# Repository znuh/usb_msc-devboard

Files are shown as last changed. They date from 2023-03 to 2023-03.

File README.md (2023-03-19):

# Devboard for USB mass storage


EDA: [KiCad7](https://www.kicad.org/)

## Parts
* MCU: [STM32F730R8Tx](https://www.st.com/en/microcontrollers-microprocessors/stm32f730r8.html) (or compatible)
* Mass storage: MicroSD via [DM3D-SF](https://www.hirose.com/product/series/DM3#) socket (attached to SDMMC1 of STM32)
* [USB3318](https://www.microchip.com/en-us/product/USB3318) USB high speed PHY
* 3.3V voltage regulator: [AP7313-33SR](https://www.diodes.com/part/view/AP7313/) or compatible
* PCB: 4 layer (Sig1, GND, 3.3V, Sig2) stackup
* 1x USB-C, 1x Micro USB
* 3x 0603 LEDs (power, user1, user2)
* 1x Button (Bootloader + user defined)
* passives: 0402 and 0603
* all componentes are on top, none on bottom

## Notes
* USB-C connector for hi-speed USB
* Micro USB connector for dev/debugging/DFU bootloader
* Testpads on bottom for UART (debugging, etc.)
* only one 13MHz crystal, connected to STM32 - MCO1 output of STM32 clocks USB PHY
* serial termination resistors in all clock lines

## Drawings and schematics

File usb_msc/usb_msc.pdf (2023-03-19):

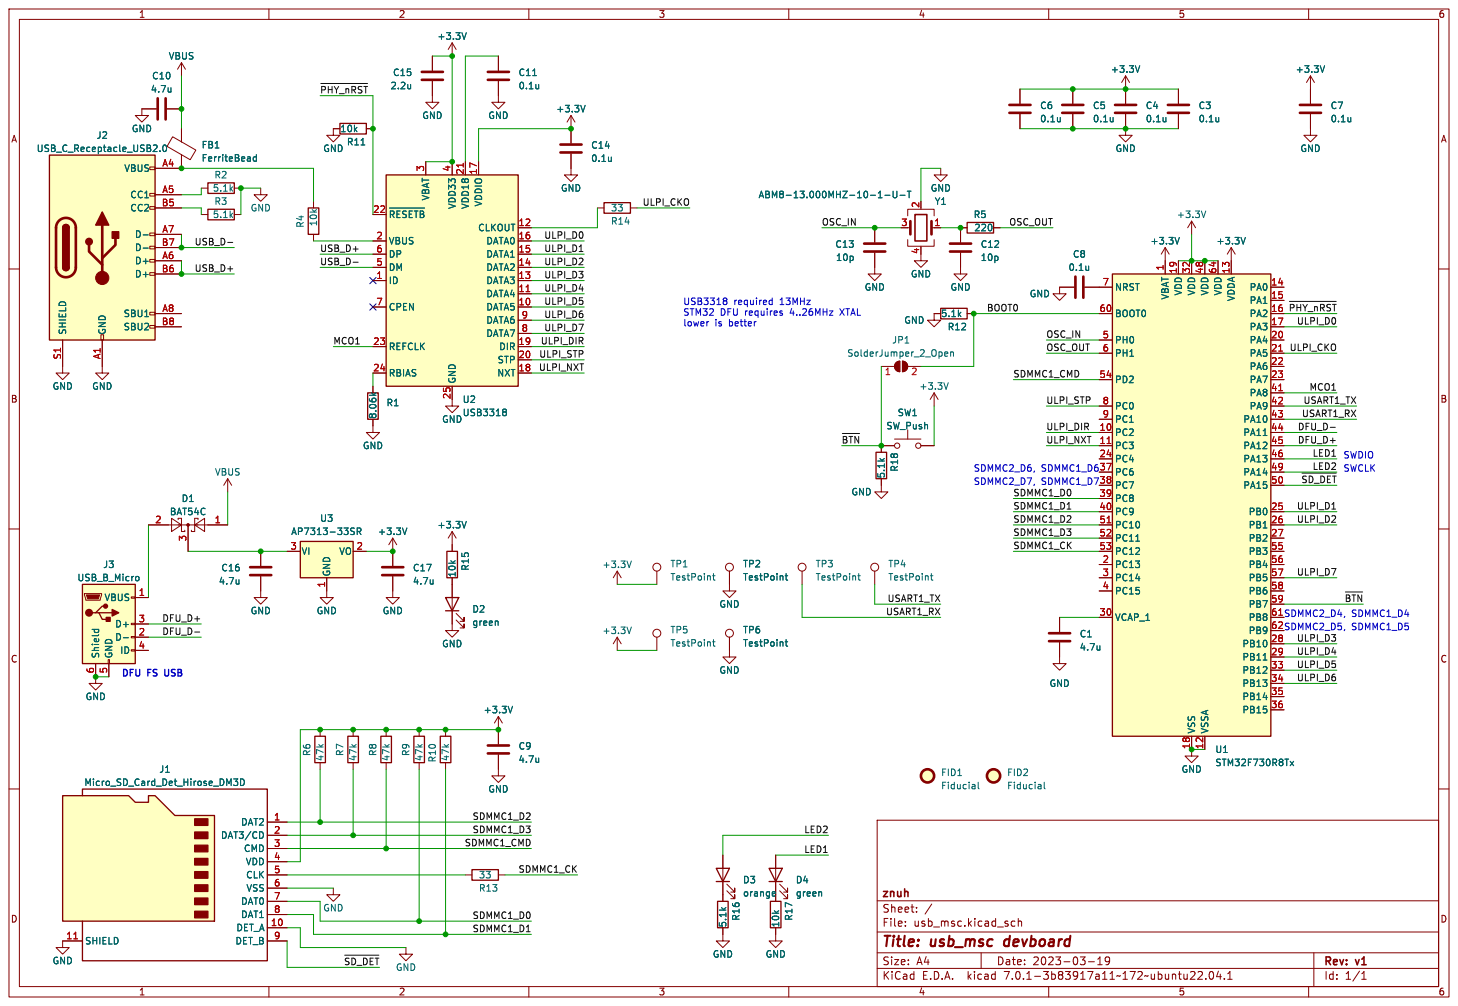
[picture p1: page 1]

4 DM 5 DP 6 CPEN 7 DATA7 8 DATA6 9 U2 USB3318 GND GND

4 DM 5 DP 6 CPEN 7 DATA7 8 DATA6 9 GND GND

1 PC2 10 PC3 11 VSSA 12 VDDA 13 PA0 14 PA1 15 PA2 16 PA3 17 VSS 18 VDD 19 PC13 2 PA4 20 PA5 21 PA6 22 PA7 23 PC4 24 PB0 25 PB1 26 PB2 27 PB10 28 PB11 29 PC14 3 VCAP_1 30 VDD 32 PB12 33 PB13 34 PB14 35 PB15 36 PC6 37 PC7 38 PC8 39 PC15 4 PC9 40 PA8 41 PA9 42 PA10 43 PA11 44 PA12 45 PA13 46 VDD 48 PA14 49 PH0 5 PA15 50 PC10 51 PC11 52 PC12 53 PD2 54 PB3 55 PB4 56 PB5 57 PB6 58 PB7 59 PH1 6 BOOT0 60 PB8 61 PB9 62 VDD 64 NRST 7 PC0 8 PC1 9 C14

1 PC2 10 PC3 11 VSSA 12 VDDA 13 PA0 14 PA1 15 PA2 16 PA3 17 VSS 18 VDD 19 PC13 2 PA4 20 PA5 21 PA6 22 PA7 23 PC4 24 PB0 25 PB1 26 PB2 27 PB10 28 PB11 29 PC14 3 VCAP_1 30 VDD 32 PB12 33 PB13 34 PB14 35 PB15 36 PC6 37 PC7 38 PC8 39 PC15 4 PC9 40 PA8 41 PA9 42 PA10 43 PA11 44 PA12 45 PA13 46 VDD 48 PA14 49 PH0 5 PA15 50 PC10 51 PC11 52 PC12 53 PD2 54 PB3 55 PB4 56 PB5 57 PB6 58 PB7 59 PH1 6 BOOT0 60 PB8 61 PB9 62 VDD 64 NRST 7 PC0 8 PC1 9 U1STM32F730R8Tx

SDMMC2_D5, SDMMC1_D5 SDMMC2_D7, SDMMC1_D7 SDMMC2_D6, SDMMC1_D6 USB3318 required 13MHz STM32 DFU requires 4..26MHz XTAL
+3.3V GND

File: usb_msc.kicad_sch Sheet: / znuh GND
green R17 10k GND

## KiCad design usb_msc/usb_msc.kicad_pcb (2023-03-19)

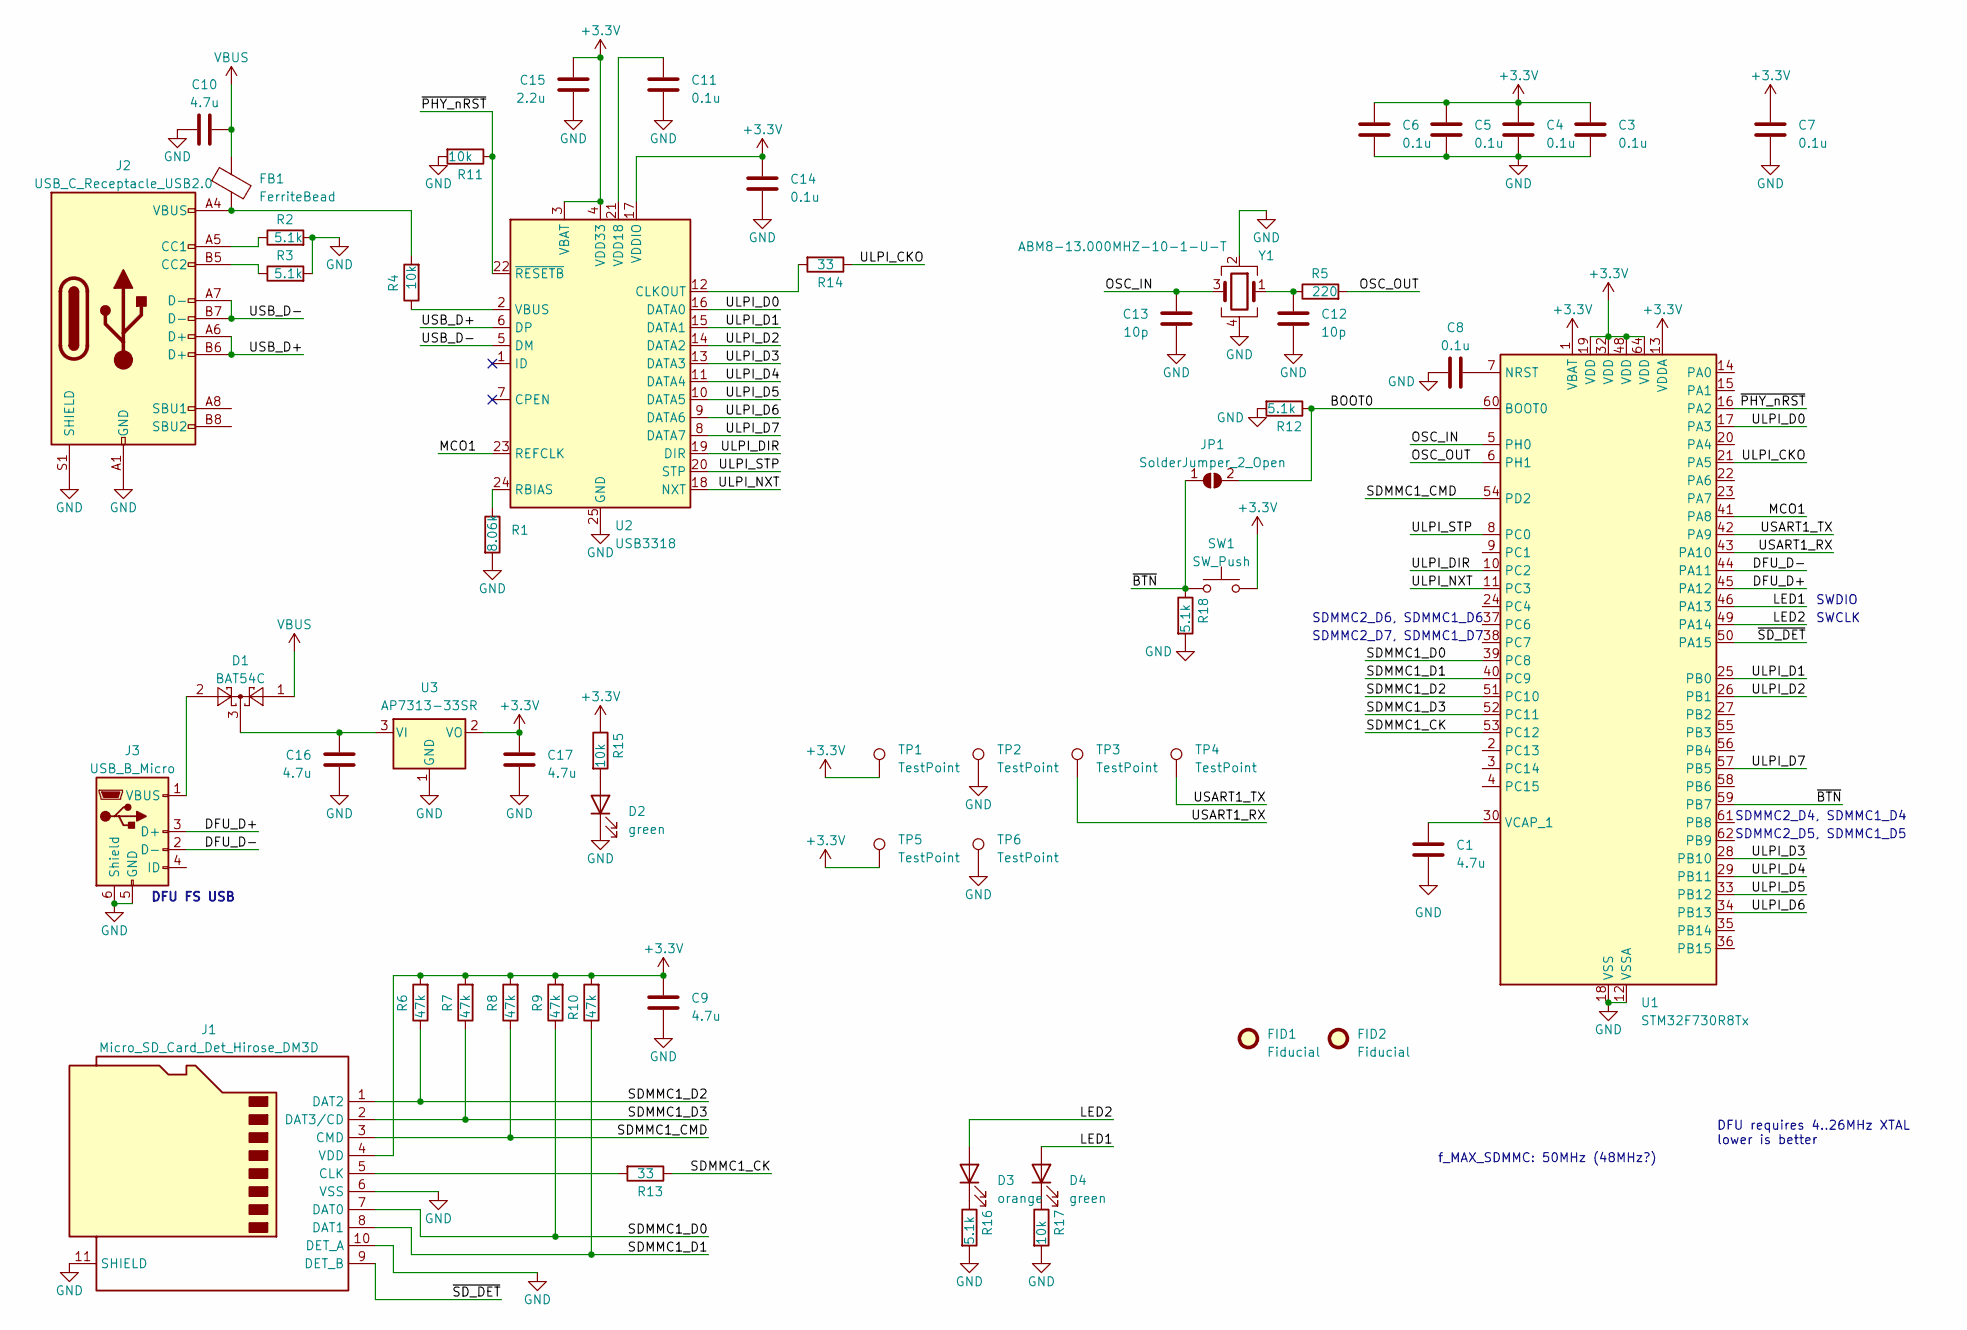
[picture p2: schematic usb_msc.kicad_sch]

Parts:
C1: 4.7u; C_0402_1005Metric
C3, C4, C5, C6, C7, C8, C11, C14: 0.1u; C_0402_1005Metric
C9, C10, C16, C17: 4.7u; C_0603_1608Metric
C12, C13: 10p; C_0402_1005Metric
C15: 2.2u; C_0402_1005Metric
D1: BAT54C; SOT-23
D2, D4: green; LED_0603_1608Metric
D3: orange; LED_0603_1608Metric
FB1: FerriteBead; L_0603_1608Metric
FID1, FID2: Fiducial; Fiducial_0.5mm_Mask1.5mm
J1: Micro_SD_Card_Det_Hirose_DM3D; microSD_HC_Hirose_DM3D-SF
J2: USB_C_Receptacle_USB2.0; USB_C_Receptacle_XKB_U262-16XN-4BVC11
J3: USB_B_Micro; USB_Micro-B_Amphenol_10103594-0001LF_Horizontal
JP1: SolderJumper_2_Open; SolderJumper-2_P1.3mm_Open_RoundedPad1.0x1.5mm
R1: 8.06k; R_0402_1005Metric
R2, R3, R12, R16, R18: 5.1k; R_0402_1005Metric
R4, R11, R15, R17: 10k; R_0402_1005Metric
R5: 220; R_0402_1005Metric
R6, R7, R8, R9, R10: 47k; R_0402_1005Metric
R13, R14: 33; R_0402_1005Metric
SW1: SW_Push; SMD_BTN
TP1, TP2, TP3, TP4, TP5, TP6: TestPoint; TestPoint_Pad_D1.0mm
U1: STM32F730R8Tx; LQFP-64_10x10mm_P0.5mm
U2: USB3318; QFN-24-1EP_4x4mm_P0.5mm_EP2.6x2.6mm_ThermalVias
U3: AP7313-33SR; SOT-23
Y1: ABM8-13.000MHZ-10-1-U-T; Crystal_SMD_Abracon_ABM8G-4Pin_3.2x2.5mm

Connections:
+3.3V: C3.2, C4.2, C5.2, C6.2, C7.2, C9.2, C14.2, C15.2, C17.1, J1.4 (VDD), R6.2, R7.2, R8.2, R9.2, R10.2, R15.1, SW1.2, TP1.1, TP5.1, U1.1 (VBAT), U1.13 (VDDA), U1.19 (VDD), U1.32 (VDD), U1.48 (VDD), U1.64 (VDD), U2.3 (VBAT), U2.4 (VDD33), U2.17 (VDDIO), U3.2 (VO)
/BOOT0: JP1.2 (B), R12.1, U1.60 (BOOT0)
/DFU_D+: J3.3 (D+), U1.45 (PA12)
/DFU_D-: J3.2 (D-), U1.44 (PA11)
/LED1: D4.2 (A), U1.46 (PA13)
/LED2: D3.2 (A), U1.49 (PA14)
/MCO1: U1.41 (PA8), U2.23 (REFCLK)
/OSC_IN: C13.2, U1.5 (PH0), Y1.3
/OSC_OUT: R5.2, U1.6 (PH1)
/SDMMC1_CK: R13.1, U1.53 (PC12)
/SDMMC1_CMD: J1.3 (CMD), R8.1, U1.54 (PD2)
/SDMMC1_D0: J1.7 (DAT0), R9.1, U1.39 (PC8)
/SDMMC1_D1: J1.8 (DAT1), R10.1, U1.40 (PC9)
/SDMMC1_D2: J1.1 (DAT2), R6.1, U1.51 (PC10)
/SDMMC1_D3: J1.2 (DAT3/CD), R7.1, U1.52 (PC11)
/ULPI_CKO: R14.1, U1.21 (PA5)
/ULPI_D0: U1.17 (PA3), U2.16 (DATA0)
/ULPI_D1: U1.25 (PB0), U2.15 (DATA1)
/ULPI_D2: U1.26 (PB1), U2.14 (DATA2)
/ULPI_D3: U1.28 (PB10), U2.13 (DATA3)
/ULPI_D4: U1.29 (PB11), U2.11 (DATA4)
/ULPI_D5: U1.33 (PB12), U2.10 (DATA5)
/ULPI_D6: U1.34 (PB13), U2.9 (DATA6)
/ULPI_D7: U1.57 (PB5), U2.8 (DATA7)
/ULPI_DIR: U1.10 (PC2), U2.19 (DIR)
/ULPI_NXT: U1.11 (PC3), U2.18 (NXT)
/ULPI_STP: U1.8 (PC0), U2.20 (STP)
/USART1_RX: TP3.1, U1.43 (PA10)
/USART1_TX: TP4.1, U1.42 (PA9)
/USB_D+: J2.A6 (D+), J2.B6 (D+), U2.6 (DP)
/USB_D-: J2.A7 (D-), J2.B7 (D-), U2.5 (DM)
/~BTN: JP1.1 (A), R18.1, SW1.1, U1.59 (PB7)
/~PHY_nRST: R11.1, U1.16 (PA2), U2.22 (~RESETB)
/~SD_DET: J1.9 (DET_B), U1.50 (PA15)
GND: C1.1, C3.1, C4.1, C5.1, C6.1, C7.1, C8.2, C9.1, C10.2, C11.1, C12.1, C13.1, C14.1, C15.1, C16.2, C17.2, D2.1 (K), J1.6 (VSS), J1.10 (DET_A), J1.11 (SHIELD), J2.A1 (GND), J2.A12 (GND), J2.B1 (GND), J2.B12 (GND), J2.S1 (SHIELD), J3.5 (GND), J3.6 (Shield), R1.2, R2.2, R3.2, R11.2, R12.2, R16.2, R17.2, R18.2, TP2.1, TP6.1, U1.12 (VSSA), U1.18 (VSS), U1.31 (VSS), U1.47 (VSS), U1.63 (VSS), U2.25 (GND), U3.1 (GND), Y1.2, Y1.4
unnamed: C12.2, R5.1, Y1.1
unnamed: D2.2 (A), R15.2
unnamed: D3.1 (K), R16.1
unnamed: D4.1 (K), R17.1
unnamed: FB1.2, J2.A4 (VBUS), J2.A9 (VBUS), J2.B4 (VBUS), J2.B9 (VBUS), R4.2
unnamed: J1.5 (CLK), R13.2
unnamed: J2.A5 (CC1), R2.1
unnamed: J2.B5 (CC2), R3.1
unnamed: D1.2, J3.1 (VBUS)
unnamed: C8.1, U1.7 (NRST)
unnamed: C1.2, U1.30 (VCAP_1)
unnamed: R14.2, U2.12 (CLKOUT)
unnamed: R1.1, U2.24 (RBIAS)
unnamed: R4.1, U2.2 (VBUS)
unnamed: C11.2, U2.21 (VDD18)
unnamed: C16.1, D1.3, U3.3 (VI)
VBUS: C10.1, D1.1, FB1.1

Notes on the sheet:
SWDIO
SDMMC2_D6, SDMMC1_D6
SDMMC2_D4, SDMMC1_D4
SWCLK
SDMMC2_D5, SDMMC1_D5
DFU FS USB
DFU requires 4..26MHz XTAL lower is better
f_MAX_SDMMC: 50MHz (48MHz?)
SDMMC2_D7, SDMMC1_D7

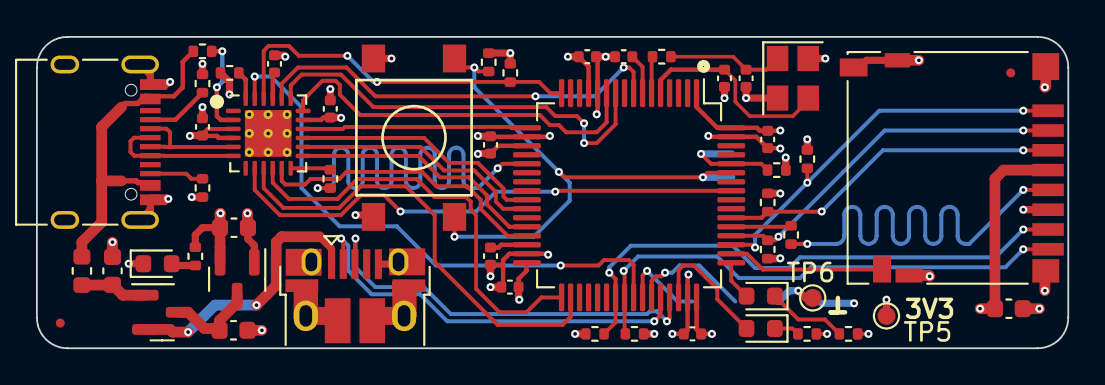
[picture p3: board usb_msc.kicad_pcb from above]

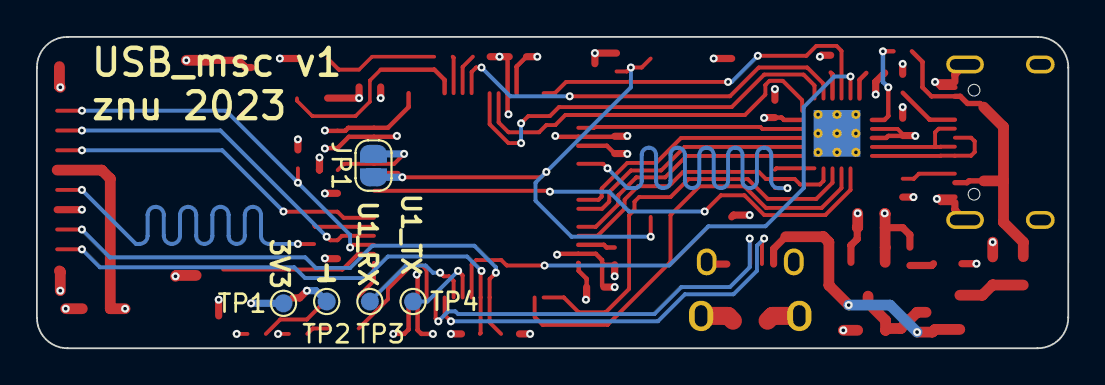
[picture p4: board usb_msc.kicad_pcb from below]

Board: 4 copper layers, 57.3 x 17.3 mm, 56 parts (5 on the bottom side), 52 nets.

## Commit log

2023-03-19 add kicad files
    [usb_msc.kicad_pcb, usb_msc.kicad_sch]
2023-03-19 add schematics as pdf
    [usb_msc.kicad_sch]
